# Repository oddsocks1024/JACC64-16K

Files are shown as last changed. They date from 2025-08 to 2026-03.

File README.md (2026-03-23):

# JACC64-16K
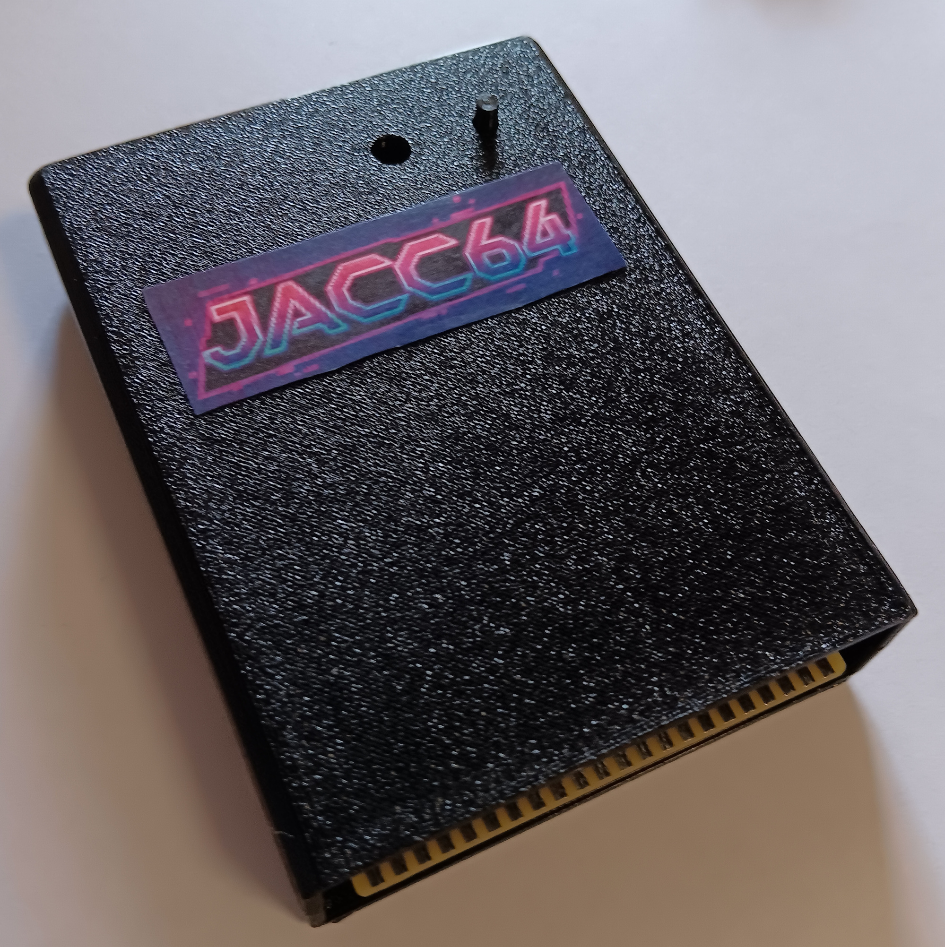
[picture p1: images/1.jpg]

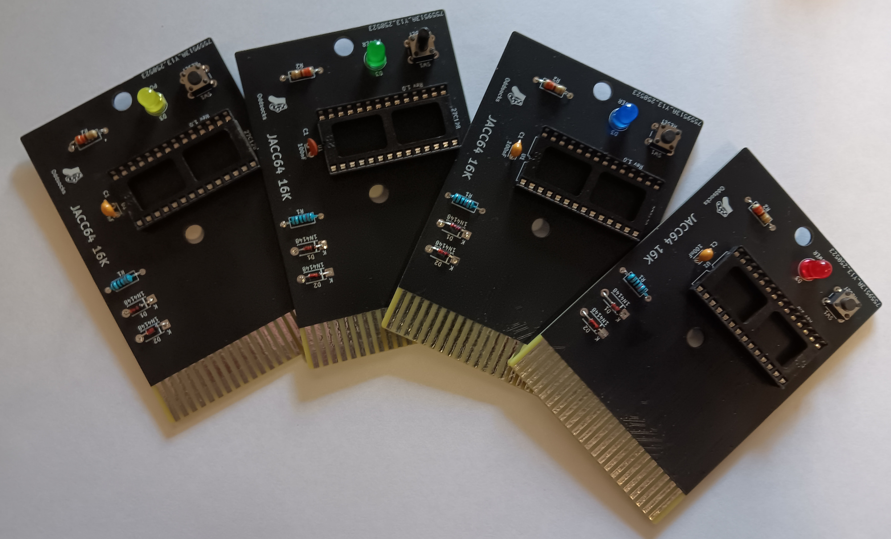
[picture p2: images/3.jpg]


## Description
JACC64-16K: Just Another Commodore Cartridge.

A simple ROM cartridge for the Commodore 64 which takes a single 16K ROM image in an EPROM/EEPROM. Thanks to [World of Jani](https://blog.worldofjani.com/?p=879) for the original circuit design.

**Features**
* Power LED
* Reset Switch

## Bill of Materials

| Qty | Component |
|:---:|---|
| 1 | 5mm LED |
| 1 | 6x6mm Tactile Push Button |
| 1 | 330Ω Axial Resistor - ¼ watt (LED) |
| 1 | 10KΩ Axial Resistor - ¼ watt |
| 2 | 1N4148 Diodes |
| 1 | 100nF Ceramic Capacitor |
| 1 | M27C128 EPROM (or compatible) |

* IC Sockets are optional.
* The LED resistor is nominally 330Ω but anything up to 1K is fine
* You will need to burn the 16K ROM image to the EPROM/EEPROM using a suitable programmer.
* Larger EPROMs/EEPROMs can be used but be sure to repeat the image to fill up the ROM.

## 3D Printable Case
A 3D printable case specifically designed for this PCB is also available. STLs are included in this repo.

* Insert the PCB into the base part of the case, making sure the holes in the PCB are aligned with the screw posts.
* Insert the reset pin into the top part of the case, then align it with the bottom part of the case.
* Use 2 x 3.5mm self-tapping screws to screw the case parts together. Max length about 15mm.

## Support Me
Everything is freely available so you can make your own PCB and case, however if you would like to support me, please see the following links.

* [My Projects](https://projects.amiga-hardware.com) - Donate on this page
* [Order the JACC64-16K PCB](https://www.pcbway.com/project/shareproject/JACC64_16K_C64_Cartridge_8e199b4f.html)
* [Order the JACC64-16K Case](https://www.pcbway.com/project/shareproject/JACC64_16K_C64_Cartridge_Case_78ec0fd1.html)

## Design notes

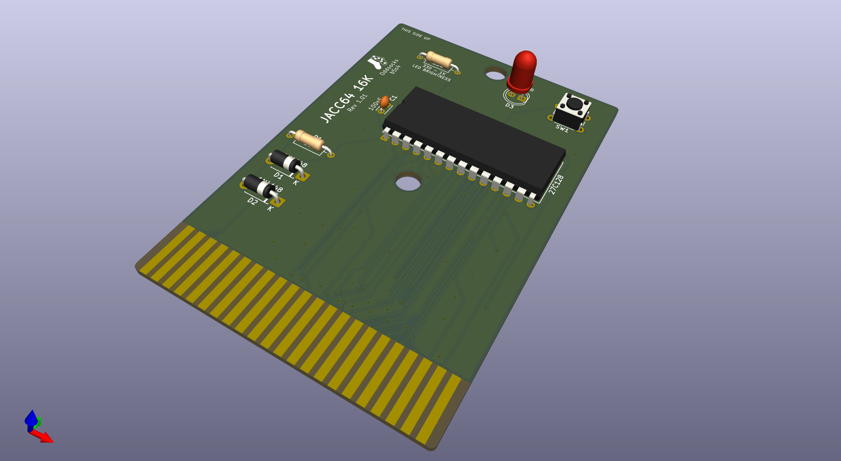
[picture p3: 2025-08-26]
images/JACC64-16K.png

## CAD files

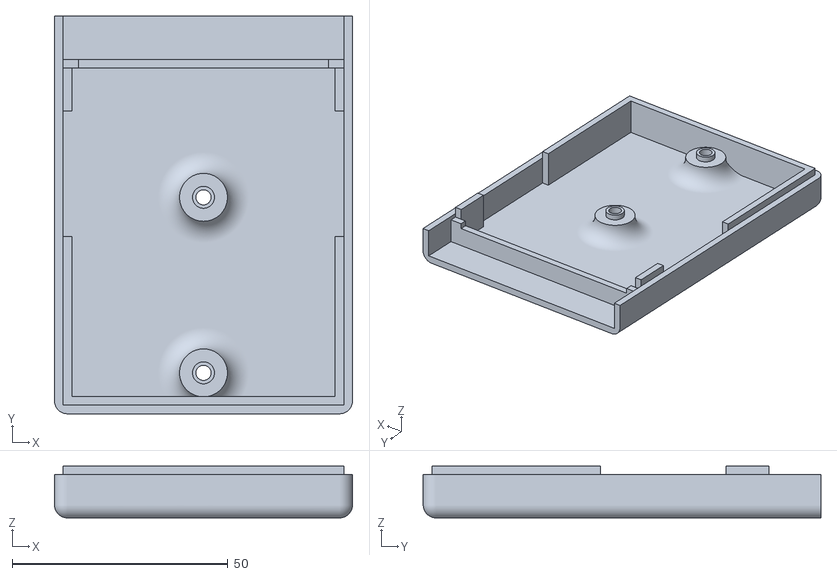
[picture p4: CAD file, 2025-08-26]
STL/JACC64-16K-Case-Bottom.stl
69.0 x 92.1 x 12.0

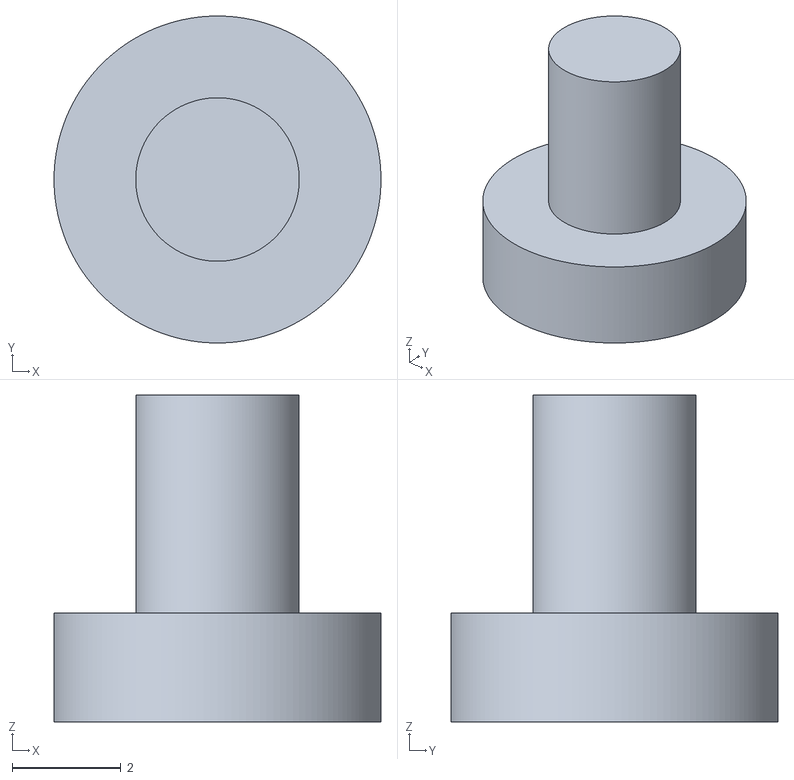
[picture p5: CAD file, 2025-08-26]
STL/JACC64-16K-Reset-Pin.stl
6.00 x 6.00 x 6.00

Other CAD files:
STL/JACC64-16K-Case-Top.stl

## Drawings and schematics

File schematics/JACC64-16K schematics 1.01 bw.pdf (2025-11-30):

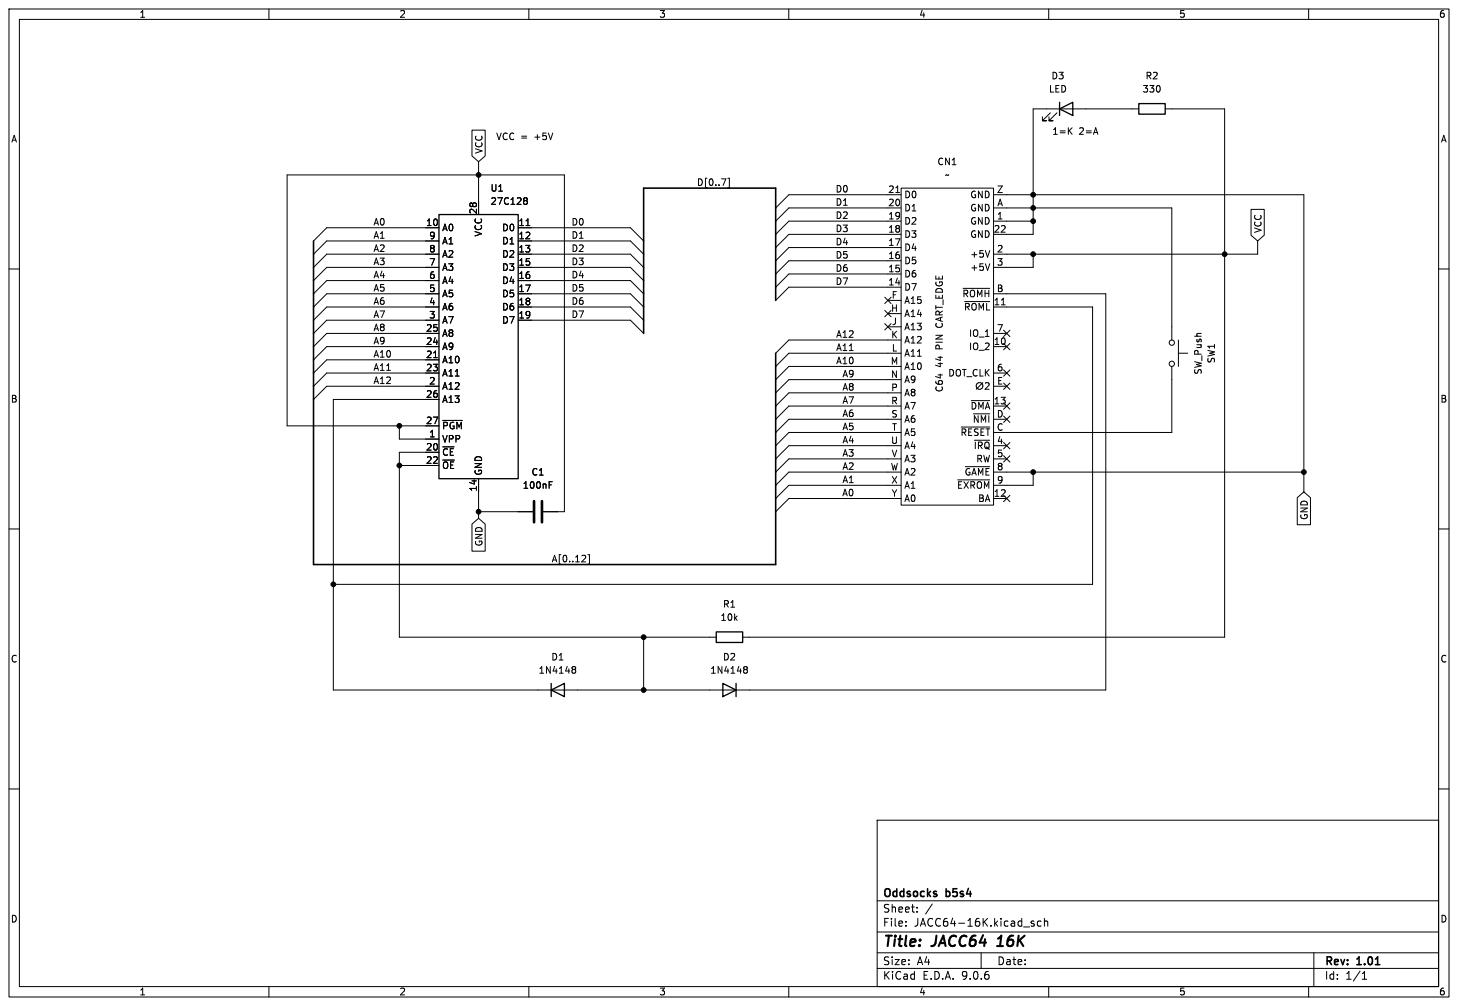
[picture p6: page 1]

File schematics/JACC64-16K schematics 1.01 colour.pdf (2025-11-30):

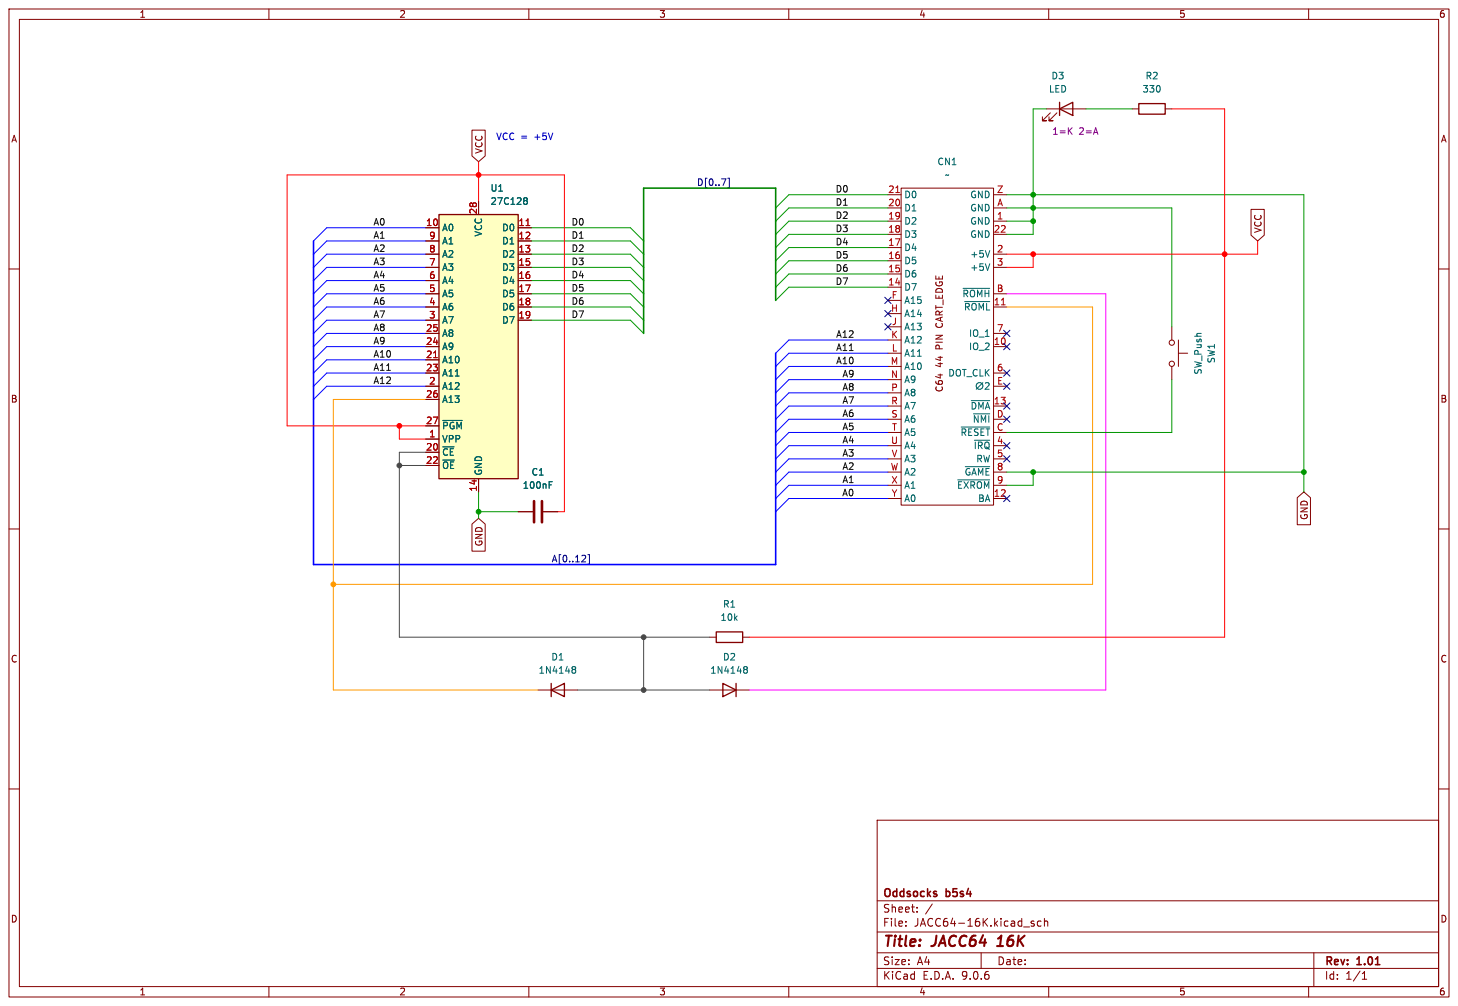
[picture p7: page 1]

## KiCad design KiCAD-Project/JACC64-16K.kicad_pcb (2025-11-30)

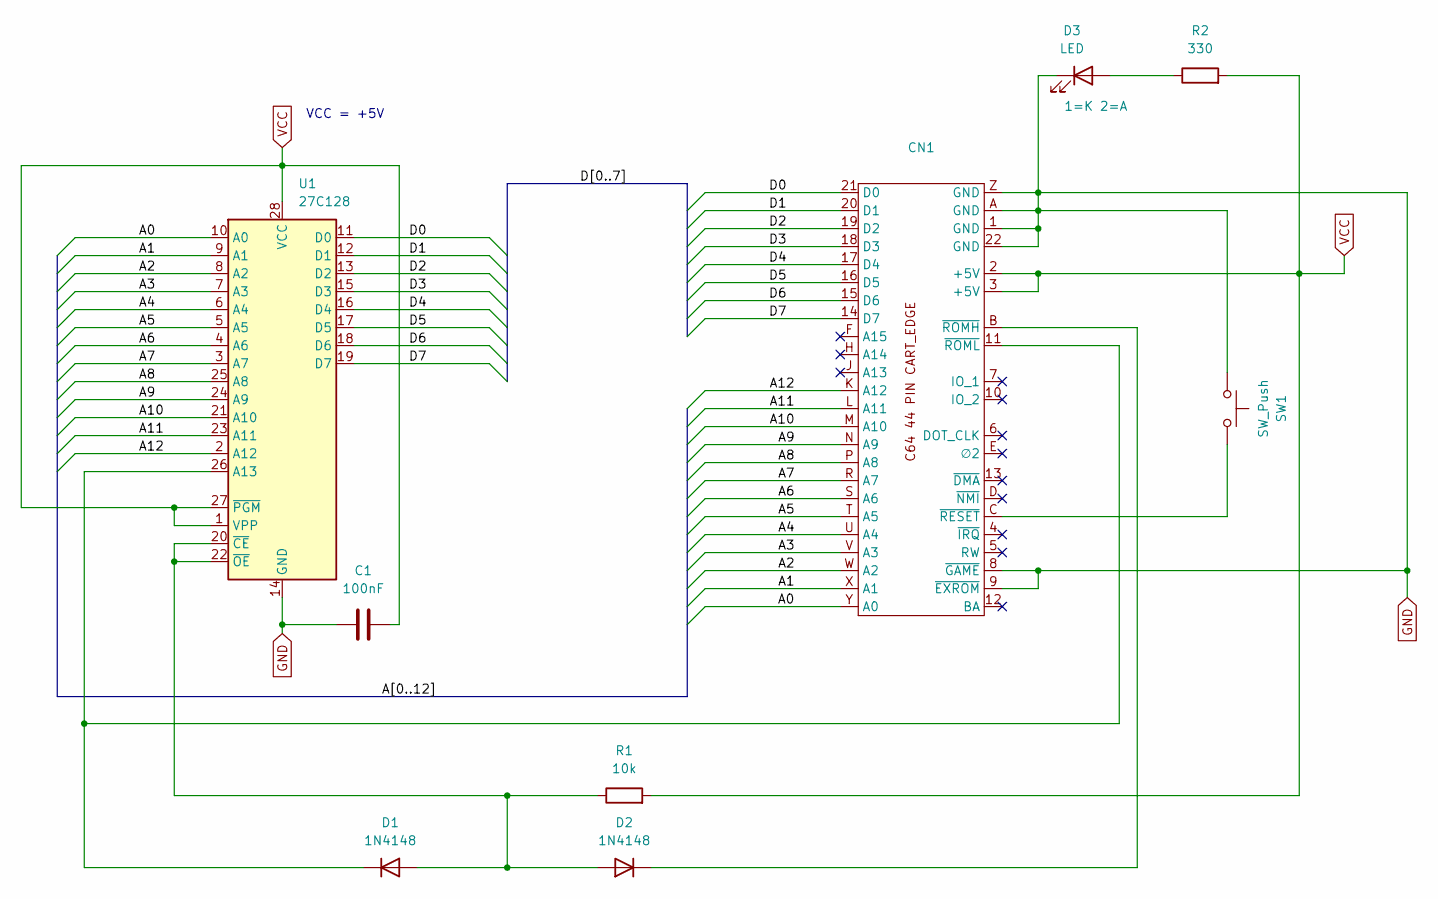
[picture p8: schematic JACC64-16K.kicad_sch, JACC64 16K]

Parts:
C1: 100nF; C_Disc_D3.0mm_W2.0mm_P2.50mm
CN1: C64 Expansion
D1, D2: 1N4148; D_DO-41_SOD81_P7.62mm_Horizontal
D3: LED; LED_D5.0mm
R1: 10k; R_Axial_DIN0207_L6.3mm_D2.5mm_P10.16mm_Horizontal
R2: 330; R_Axial_DIN0207_L6.3mm_D2.5mm_P10.16mm_Horizontal
SW1: SW_Push; SW_PUSH_6mm
U1: 27C128; DIP-28_W15.24mm

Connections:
/A0: CN1.Y (A0), U1.10 (A0)
/A1: CN1.X (A1), U1.9 (A1)
/A2: CN1.W (A2), U1.8 (A2)
/A3: CN1.V (A3), U1.7 (A3)
/A4: CN1.U (A4), U1.6 (A4)
/A5: CN1.T (A5), U1.5 (A5)
/A6: CN1.S (A6), U1.4 (A6)
/A7: CN1.R (A7), U1.3 (A7)
/A8: CN1.P (A8), U1.25 (A8)
/A9: CN1.N (A9), U1.24 (A9)
/A10: CN1.M (A10), U1.21 (A10)
/A11: CN1.L (A11), U1.23 (A11)
/A12: CN1.K (A12), U1.2 (A12)
/D0: CN1.21 (D0), U1.11 (D0)
/D1: CN1.20 (D1), U1.12 (D1)
/D2: CN1.19 (D2), U1.13 (D2)
/D3: CN1.18 (D3), U1.15 (D3)
/D4: CN1.17 (D4), U1.16 (D4)
/D5: CN1.16 (D5), U1.17 (D5)
/D6: CN1.15 (D6), U1.18 (D6)
/D7: CN1.14 (D7), U1.19 (D7)
GND: C1.1, CN1.1 (GND), CN1.8 (~GAME), CN1.9 (~EXROM), CN1.22 (GND), CN1.A (GND), CN1.Z (GND), D3.1 (K), SW1.1, U1.14 (GND)
unnamed: CN1.C (~RESET), SW1.2
unnamed: CN1.B (~ROMH), D2.1 (K)
unnamed: CN1.11 (~ROML), D1.1 (K), U1.26 (A13)
unnamed: D1.2 (A), D2.2 (A), R1.1, U1.20 (~CE), U1.22 (~OE)
unnamed: D3.2 (A), R2.1
VCC: C1.2, CN1.2 (+5V), CN1.3 (+5V), R1.2, R2.2, U1.1 (VPP), U1.27 (~PGM), U1.28 (VCC)

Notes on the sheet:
VCC = +5V

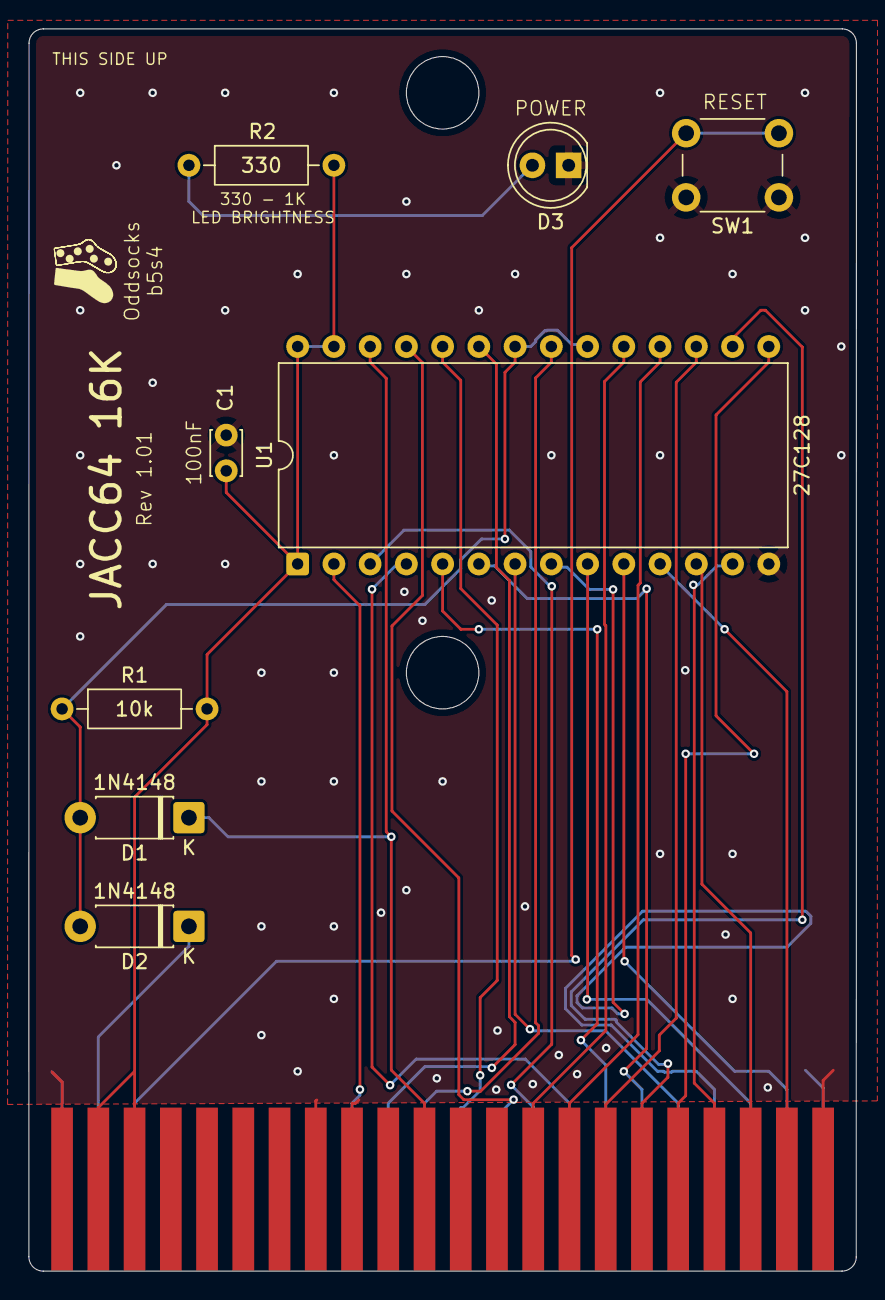
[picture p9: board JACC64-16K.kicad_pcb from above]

Board: 2 copper layers, 58.0 x 87.1 mm, 9 parts (0 on the bottom side), 28 nets.

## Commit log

2025-11-09 Added gerbers and updated README.md
    [JACC64-16K-B_Cu.gbl, JACC64-16K-B_Mask.gbs, JACC64-16K-B_Paste.gbp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]
2025-11-30 Added PDF schematics
    [JACC64-16K.kicad_pcb, JACC64-16K.kicad_sch]
